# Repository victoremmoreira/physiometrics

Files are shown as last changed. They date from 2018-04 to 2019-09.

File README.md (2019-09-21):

<p align="center">
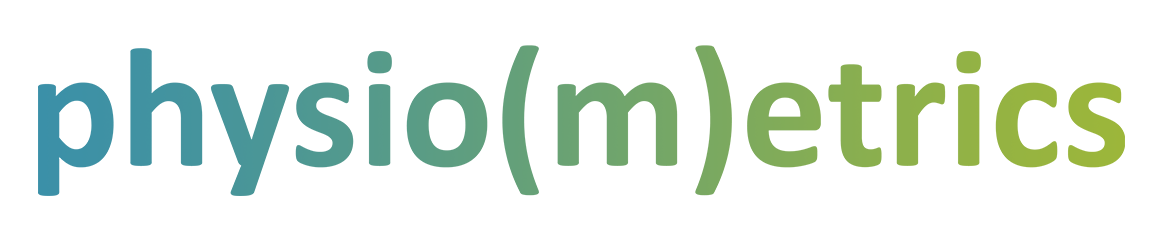
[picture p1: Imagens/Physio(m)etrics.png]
    

  <h3 align="center">Projeto Physiometrics</h3>
</p>

<br><b> Autor</b>: Victor Moreira (UFPR) </br>
<br><b>Colaborador</b>: Rodrigo Carvalho (UFPA) </br>
<br><b>Orientadora</b>: Maria Lúcia Okimoto (PPG-MEC UFPR) </br>

<b> Sobre </b> : Este é o resultado da pesquisa de Mestrado em Design de Victor Moreira. O Projeto Phsiometrics é composto por Hardware e Software que tem como objetivo principal a mensuração de emoções fisiológicas de jogadores de videogame. O diferencial dessa ferramenta é o baixo custo, replicabilidade e possibilidade de modificação, incrementação e evolução. 

<b>Dissertação de Mestrado</b>
https://www.prppg.ufpr.br/siga/visitante/trabalhoConclusaoWS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

<b>Artigos Científicos </b>
https://link.springer.com/chapter/10.1007/978-3-319-94944-4_14

<b>Página no Facebook</b>
https://www.facebook.com/physiometrics

<!-- ABOUT THE PROJECT -->
## Como usar

# 1° Passo: Reconhecimento do sistema
Utilizamos o Arduino Nano para ligar três sensores: batimentos cardíacos (HR), resposta galvânica da pele (GSR) e eletromiograma (EMG); e realizamos as ligações elétricas (FIGURA 1). Nesse esquema as linhas pretas representam os fios ligados ao GND, as linhas vermelhas os fios ligados a 3V3 (ou 3,3 volts) e as linhas amarelas ligadas nas portas lógicas. Os fios pretos e vermelhos fornecem energia para os sensores, enquanto que os fios amarelos enviam os dados coletados pelos sensores

<p align="center">
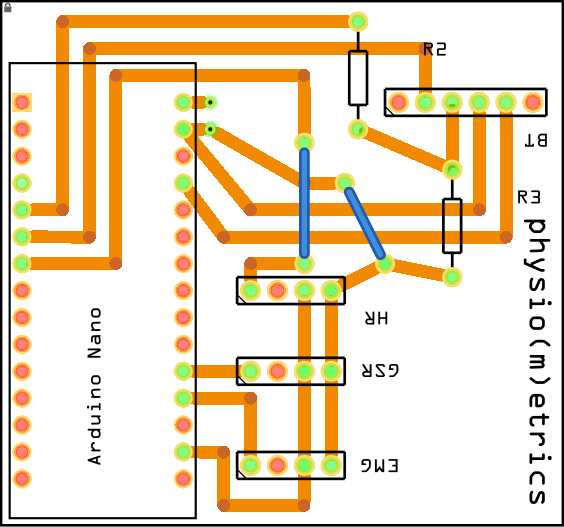
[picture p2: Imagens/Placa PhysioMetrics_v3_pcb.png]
    

<p align="center"> FIGURA 1: Ligações elétricas dos sensores de HR e GSR no Arduino Uno.
FONTE: Elaborado pelo autor. </p>
</p>

### Links para Comprar os Dispositivos

<br><b>Arduino Nano</b></br>
https://www.filipeflop.com/produto/placa-nano-v3-0-cabo-usb-para-arduino/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

<br><b>Grove - Ear-clip Heart Rate Sensor</b></br>
https://www.seeedstudio.com/Grove-Ear-clip-Heart-Rate-Sensor-p-1116.html

<br><b>Grove - GSR sensor</b></br>
https://www.seeedstudio.com/Grove-GSR-sensor-p-1614.html

Após conectar o Arduino ao computador via porta USB, torna-se possível a comunicação Arduino-Computador. Para usar o código que projetamos para o Reconhecimento do Sistema é necessário instalar um complemento no Arduino IDE. Através do link https://github.com/jrullan/neotimer é possível baixar o Timer without delay-master, esse complemento fornece a possibilidade de imprimir dados temporais mais exatos. No caso da nossa aplicação iremos imprimir 10 dados por segundo, e por isso usamos esse complemento a fim de tornar os dados mais consistentes temporalmente.

No código para o Arduino programamos duas formas de saída de dados, uma para a aplicação Java (na linha 86) e outra para o Reconhecimento do sistema (na linha 98). Na FIGURA 2 o código do Arduino está do lado direito, nele é possível verificar que as linhas 89 até 96 estão comentadas para que não interfiram na visualização dos dados. Do lado esquerdo da FIGURA 2 está aberto a função Plotter Serial do Arduino IDE, verificamos que o sensor HR em Azul e o GSR em Vermelho. Esse teste preliminar serve para verificar as respostas dos sensores, se algum deles não estiver ligado ou estiver com defeito, será possível verificar esse tipo de erro.

<p align="center">
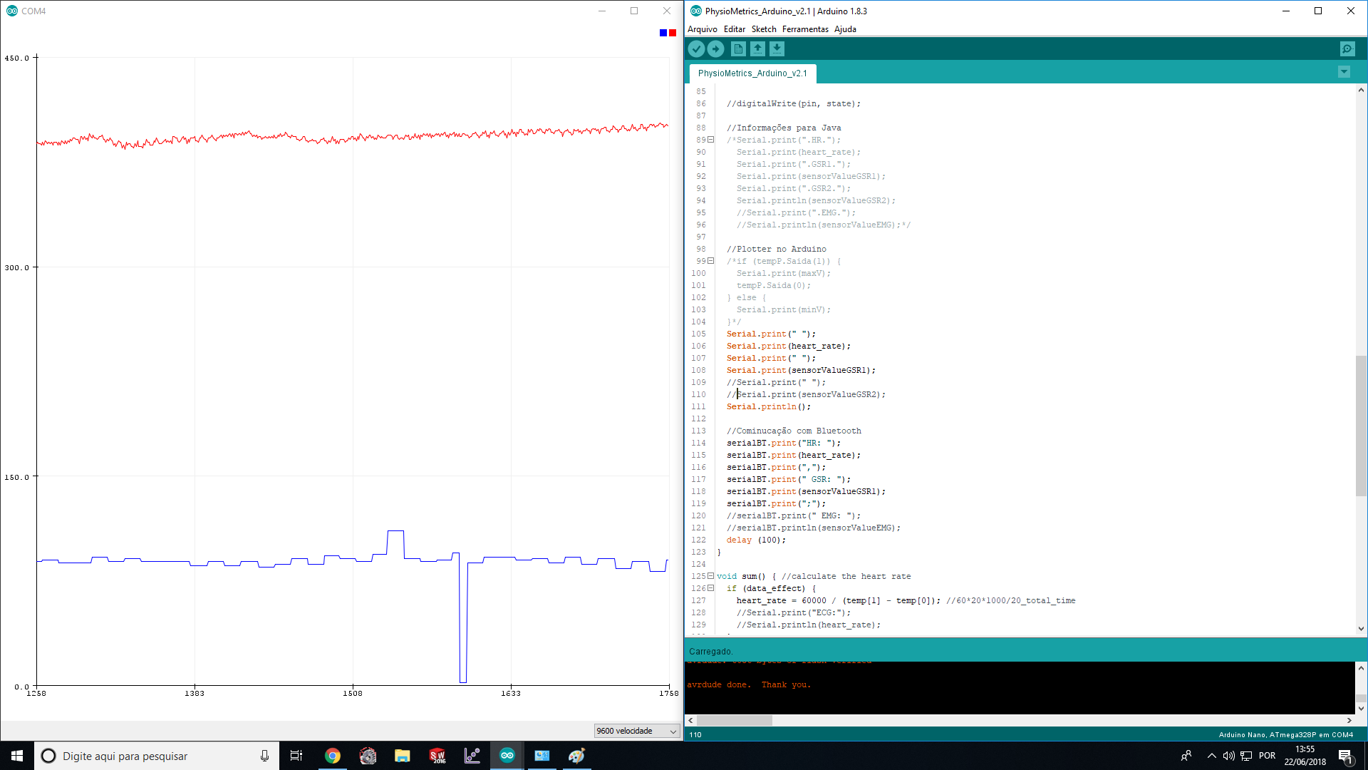
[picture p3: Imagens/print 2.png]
    

<p align="center"> FIGURA 2: Reconhecendo o sistema. 
FONTE: Elaborado pelo autor </p>
</p>

# 2° Passo: Coleta de dados

Antes de começar esse passo, é necessário reenviar o código para o Arduino “Comentando” as impressões para o Plotter do Arduino e “Descomentando” as Informações para o Java. Dentro da pasta do projeto (Programa Java) estão todos os arquivos necessários para executar o programa Physiometrics, que pode ser executado diretamente pelo arquivo Sensor.jar na pasta \dist. Na pasta raiz estão todos os arquivos necessários para abrir o projeto no programa NetBeans. Ao abrir o projeto é necessário importar todas as bibliotecas contidas na pasta \lib, e em Propriedades do Projeto – Executar – Opções de VM, colocar o caminho para a pasta \cv do computador. Ao executar o programa, abre-se a tela ilustrada na FIGURA 3. Essa tela é composta por 3 principais zonas: Na zona superior há um espaço para colocar algumas informações da coleta de dados como: Nome do Projeto, Indivíduo, Coleta, Número e Pesquisador. Abaixo, em “Dados”, são exibidos os dados em tempo real vindos dos sensores do Arduino. Na zona central à esquerda é exibido o vídeo da webcam em tempo real. E ao lado direito, alguns comandos para a comunicação Arduino-Computador, o primeiro comando é referente à porta serial que o Arduino está conectado, a segunda Conecta ou Desconecta o recebimento de dados do Arduino, o botão “Start” faz começar o processo de gravação dos dados e o botão “Stop” interrompe a gravação.

<p align="center">
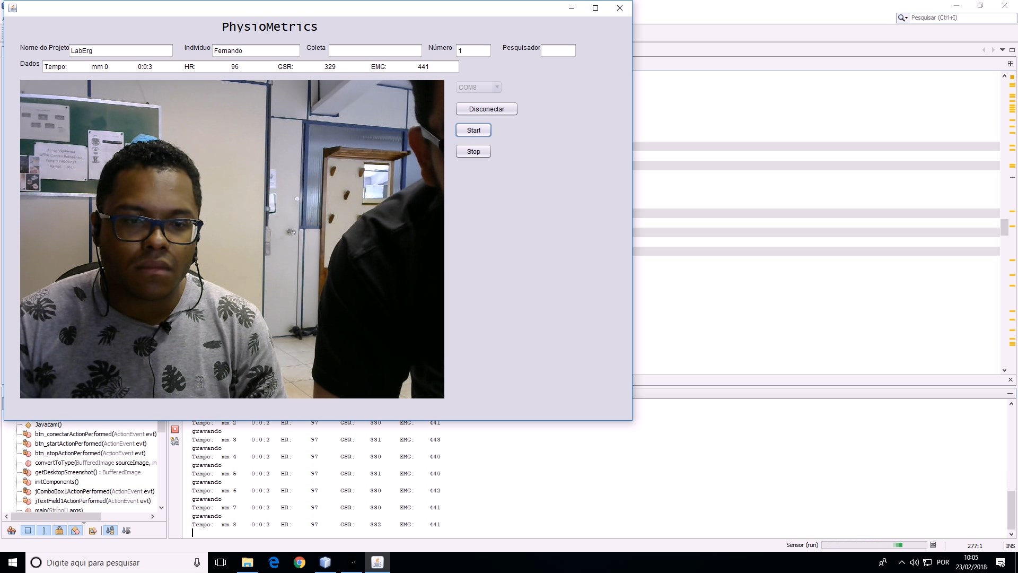
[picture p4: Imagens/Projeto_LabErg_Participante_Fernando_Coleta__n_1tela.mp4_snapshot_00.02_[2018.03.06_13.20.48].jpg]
    

<p align="center"> FIGURA 3: Execução do programa Physiometrics através do NetBeans. 
FONTE: Elaborado pelo autor </p>
</p>

Como resultado são gerados 3 arquivos, um com o vídeo do gameplay (ou da tela do computador), um vídeo da webcam e um arquivo .xls com os dados fisiológicos. Os dois vídeos têm a mesma duração e os dados fisiológicos começam a ser gravados no início do vídeo, portanto estes dados estão sincronizados.

<!-- CONTACT -->
## Contact

Victor Moreira - victoremmoreira@gmail.com

Project Link: [https://github.com/victoremmoreira/physiometrics](https://github.com/victoremmoreira/physiometrics)

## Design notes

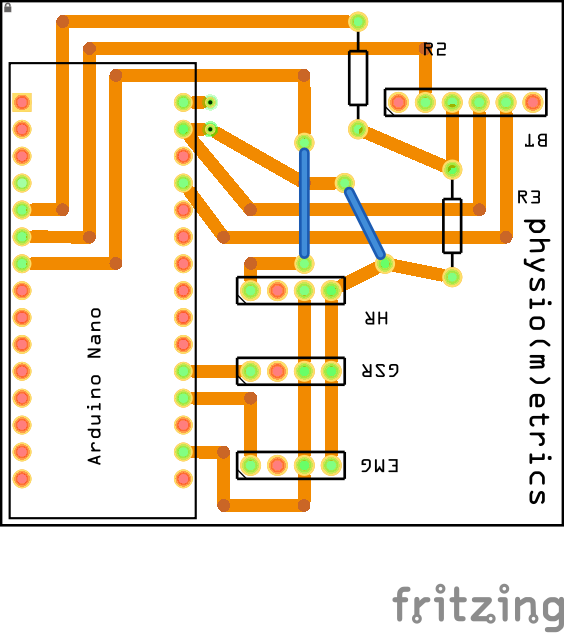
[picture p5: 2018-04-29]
Hardware/Placa PhysioMetrics_v3_pcb.png

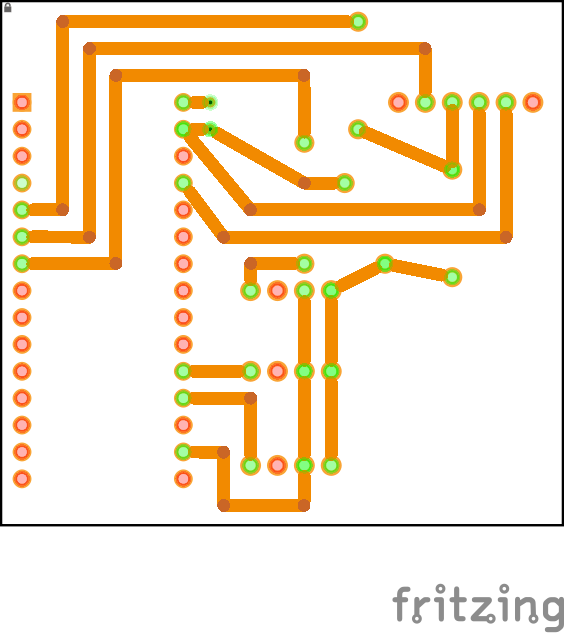
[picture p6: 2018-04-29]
Hardware/Placa PhysioMetrics_v3_pcb_ligações.png

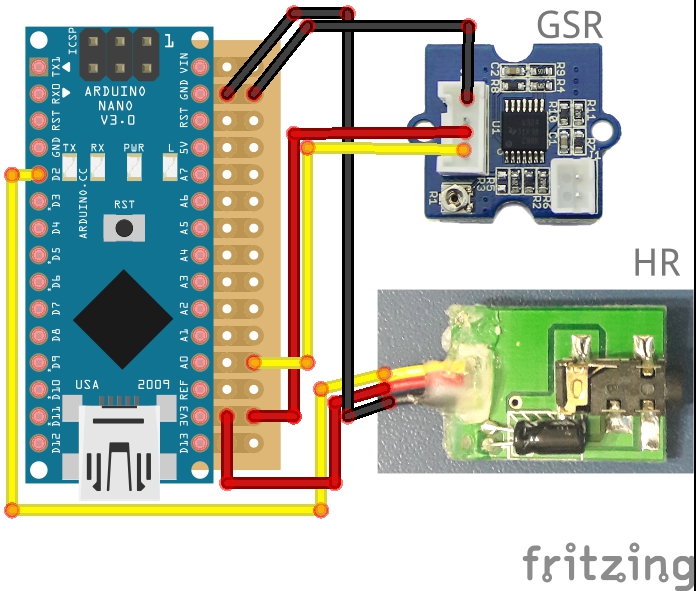
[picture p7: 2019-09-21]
Imagens/Placa PhysioMetrics_v3_HReGSR_bb.jpg

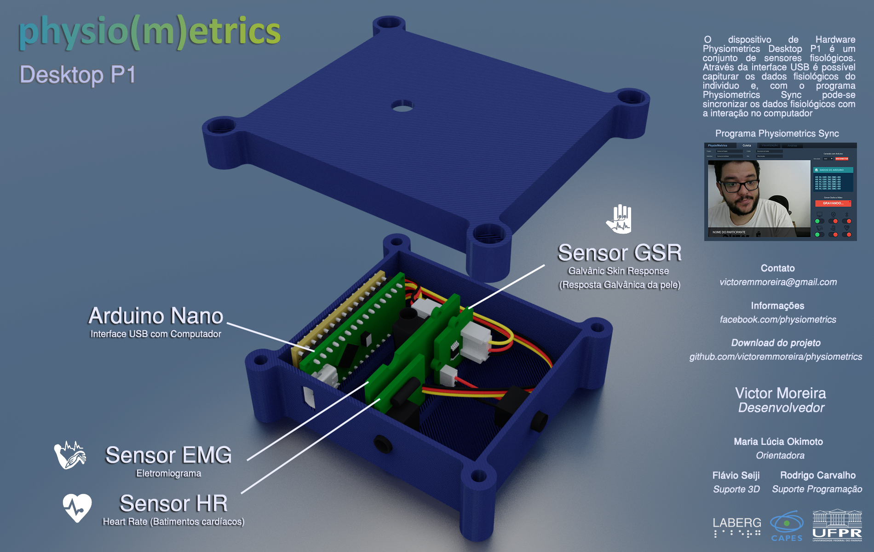
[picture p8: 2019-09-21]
Imagens/Physiometrics_Desktop_Apresentacao.jpg

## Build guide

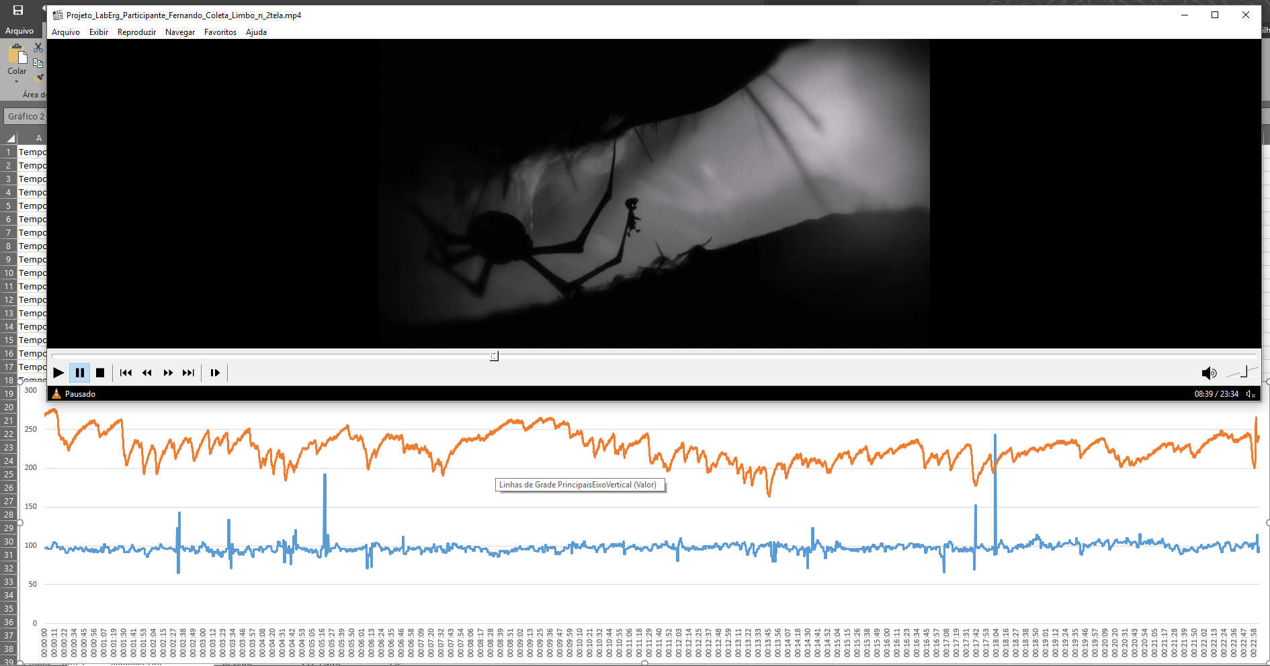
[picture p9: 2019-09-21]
Imagens/Print_gameplay_Fernando.png

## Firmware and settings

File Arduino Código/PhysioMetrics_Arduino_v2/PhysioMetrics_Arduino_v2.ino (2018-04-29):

  #include <Crescer.h> //Biblioteca pra contar tempo
#include <SoftwareSerial.h> //Biblioteca para Bluetooth

//Para Plotar no Arduino
Tempora tempP;
int maxV = 600;
int minV = 200;

//Comunicação com Bluetooth
SoftwareSerial serialBT (10, 11); // RX, TX
String textoRecebido = "";
unsigned long delay1 = 0;
unsigned long command = 0;

unsigned char pin = 13;//Led do Arduino
unsigned char counter=0;
unsigned int heart_rate=2; //Pino Digital 2 para HR
unsigned long temp[2];
unsigned long sub=0;
volatile unsigned char state = LOW;
bool data_effect=true;
const int max_heartpluse_duty=1000;
//you can change it follow your system's request.2000 meams 2 seconds. 
//System return error if the duty overtrip 2 second.

//GSR 3.3v
const int GSR = A0; //Pino analógico para o GSR
int thresholdGSR=0;
int sensorValueGSR;

//EMG 3.3v
const int EMG = A1; //Pino analógico para o EMG
int sensorValueEMG;


void setup(){
  Serial.begin(9600);
  serialBT.begin(115200);//Iniciando Porta do Bluetooth
  pinMode(pin, OUTPUT);
  array_init();
  attachInterrupt(0, interrupt, RISING);//set interrupt 0,digital port 2

//GSR
  long sum=0;
  for(int i=0;i<500;i++){ //500
    sensorValueGSR=analogRead(GSR);
    sum += sensorValueGSR;
//EMG
    sensorValueEMG=analogRead(EMG);
  }
  thresholdGSR = sum/500;
//Plotar Gráfico na IDE do Arduino
   tempP.defiSP(1000);// tempo do marcador = 1seg
}
void loop(){
  //GSR
  int temp;
  sensorValueGSR=analogRead(GSR);
  temp = thresholdGSR - sensorValueGSR;
  if(abs(temp)>50){// difereça maior q 50
    sensorValueGSR=analogRead(GSR);
    temp = thresholdGSR - sensorValueGSR;
  }
  
  //EMG
  sensorValueEMG=analogRead(EMG);
  
  digitalWrite(pin, state);
  
  //Informações para Java
  /*Serial.print(".HR.");
  Serial.print(heart_rate);
  Serial.print(".GSR.");
  Serial.print(sensorValueGSR);
  Serial.print(".EMG.");
  Serial.println(sensorValueEMG);*/
  
  //Plotter no Arduino
  if (tempP.Saida(1)){
    Serial.print(maxV);
    tempP.Saida(0);
  }else{
    Serial.print(minV);
  }
  Serial.print(" ");
  Serial.print(heart_rate);
  Serial.print(" ");
  Serial.print(sensorValueGSR);
  Serial.print(" ");
  Serial.print(analogRead(A1));
  Serial.println();

//Cominucação com Bluetooth
  serialBT.print("HR: ");
  serialBT.print(heart_rate);
  serialBT.print(",");
  serialBT.print(" GSR: ");
  serialBT.print(sensorValueGSR);
  serialBT.print(";");
  serialBT.print(" EMG: ");
  serialBT.println(sensorValueEMG); 
  delay (100);
}

void sum(){ //calculate the heart rate
  if(data_effect){
      heart_rate=60000/(temp[1]-temp[0]);//60*20*1000/20_total_time 
      //Serial.print("ECG:");
      //Serial.println(heart_rate);
  }
   data_effect=1;//sign bit
}
void interrupt(){
    temp[counter]=millis();
    state = !state;    
    //Serial.println(counter,DEC);
    //Serial.println(temp[counter]);
    switch(counter){
       case(0):
       sub=temp[counter]-temp[1];
       //Serial.println(sub);
       break;
       default:
       sub=temp[counter]-temp[counter-1];
       //Serial.println(sub);
       break;
      }
    if(sub>max_heartpluse_duty)//set 2 seconds as max heart pluse duty
      {
        data_effect=0;//sign bit
        counter=0;
        //Serial.println("Heart rate measure error,test will restart!" );
        array_init();
       }
    if (counter==1&&data_effect){
      counter=0;
      sum();
    }else if(counter!=1&&data_effect)
    counter++;
    else{
      counter=0;
      data_effect=1;
    }
}
void array_init(){
  for(unsigned char i=0;i!=1;++i){
    temp[i]=0;
  }
  temp[1]=millis();
}

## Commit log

2018-04-29 Programa Funcionando
    29-04-2018 (Atualizado no Dropbox)
    Erros:
    javaw.exe fica execuantado quando usado a versão .jar
    Logs de erro no final da coleta de dados, mas isso não afeta a coleta
    [Projeto__Participante__Coleta__n_.xls]
2018-04-29 Colocando todos os Artigos Importantes do Projeto
    [Placa PhysioMetrics_v3.fzz, Projeto__Participante__Coleta__n_.xls]
2019-09-21 Imagens
    Criação da pasta Imagens, anexo algumas imagens para readme
